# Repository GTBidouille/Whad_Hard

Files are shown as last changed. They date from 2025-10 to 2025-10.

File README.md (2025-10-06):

Bonjour, j'ai commencé à regarder la partie sniffer 40 canaux pour que cela puisse être utilisé par Whad

au début j'étais parti sur l'idée de faire 40 dongles et de les coller sur un hub usb mais je n'ai pas trouvé de hub usb assez grand, donc je serai parti sur une cascade de hub usb. Il aurait fallu gérer les tensions puis je me suis dit que peut être on pouvait faire differement

je suis parti dans l'idée de passer par un microntrolleur qui pourrait parler via SPI au module rf52840 ( en passant par la partie DMA, soit en demander au module de me prévenir quand il a des données, soit en faisant une lecture réguliere)

après mes recherches, je penche pour un STM32 ( H7,F7 ou encore H5 car ils peuvent gérer 6 bus SPI different). Cela me permettrait de limiter le nombre de CS ( en gros je lis les modules 1 de chaque carte enfant), je peux me servir du DMA pour limiter l'utilisation des modules RF, je peux buffeuriser, la vitesse est suffisante pour gerer mes 40 modules ( 5 x 8 en fait) et du coup je peux donner un résultat des 40 canaux en une seule fois.

je pense que je dois pouvoir avoir un CS commun pour les cartes sans avoir à passer par une porte NAND par exemple, il faut juste que je fasse attention au pull-up ou pull-down 

concernant la carte, j'ai choisi  la NUCLEO-F767ZI (STM32F767ZI) car elle semble convenir au besoin pour un cout plus bas que les autres. Le STM32F767ZI peut revenir à 11€ piece et la NUCLEO-F767ZI on peut la trouver à 23€

pour la partie utilisation du rf52840, je vais me baser sur le pdf schematics and PCB ainsi que sur la partie datasheet. Le cout d'un rf5280 est entre 4 et 9 €

questions: 
	- est ce que l'on part sur des antennes PCB, céramiques ou filaire
	- je pense partir sur du polling régulier mais je pourrais gérer les flux via des INT ( peut se modifier sans avoir a toucher au PCB)

je vais mettre 

broches utilisées sur le F767ZI 

pour la partie SPI ( tous en full duplex master)
| bus SPI | Miso | Mosi | CLK |
|---|---|---|---|
| SPI1 | PA6 | PA7 | PA5 | 
| SPI2 | PC2 | PC1 | PB10 | 
| SPI3 | PC11 | PB2 | PC10 | 
| SPI4 | PE5 | PE6 | PE2 | 
| SPI5 | PF8 | PF9 | PF7 | 

pour la partie CS : 
- CS1:PF13
- CS2:PF14
- CS3:PF15
- CS4:PG0
- CS5:PG1
- CS6:PE7
- CS7:PE8
- CS8:PE9

pour la partie présence
- P1:PF0
- P2:PF1
- P3:PF2
- P4:PF3
- P5:PF4

pour chaque SPI, le DMA sera activé aussi bien en TX que RX. On peut choisir le mode normal ou circular, je pense que normal est plus adapté

sur le rf52840

- p1.04 : Mosi
- p1.02 : CLK
- p1.06 : Miso
- p1.09 : /CS

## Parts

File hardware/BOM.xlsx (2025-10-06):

nom | valeur | taille | ref | nombre
X1 | 32Mhz | 2016 | C37635331 | 1
X2 | 32.768Khz | 2012 | C96341 (https://www.lcsc.com/product-detail/C96341.html)
C1, C2,C17,C18 | 12pf | 603 | C5448886 | 4
C11 | 100pf | 603
L1 | 4,7nH | 603 | C37634064 (https://www.lcsc.com/product-detail/C37634064.html)
R1 | O | 603
C3 | 0,8pF | 603
C4 | 0,5pF | 603
C26 | 1,5pF | 603
c9 | 820pF | 603
C8,C5 | 100nF | 603
R2 | 10Kohm | 603
C9 | 820pF | 603
C16 | 47nF | 603
L2,L4 | 10µH | 603 | C86083
L3 | 15nH | 402 | C381880 (https://www.lcsc.com/product-detail/C381880.html)
C15 | 1µF | 603
led1 | blanc | 603
led2_r | rouge | 603
led2_g | vert | 603
led2_b | bleu | 603
R3,R4,R5,R6 | 220 | 603
C12 | 4,7µF | 603
 |  | 1206 | C89334
 | rf52840 | 73-VFQFN | https://www.digikey.fr/fr/products/detail/nordic-semiconductor-asa/NRF52840-QIAA-R/7725407

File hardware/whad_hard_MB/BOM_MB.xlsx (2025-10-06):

nom | valeur | taille | ref | nombre
PCIE |  | X1 | C5711219 | 5

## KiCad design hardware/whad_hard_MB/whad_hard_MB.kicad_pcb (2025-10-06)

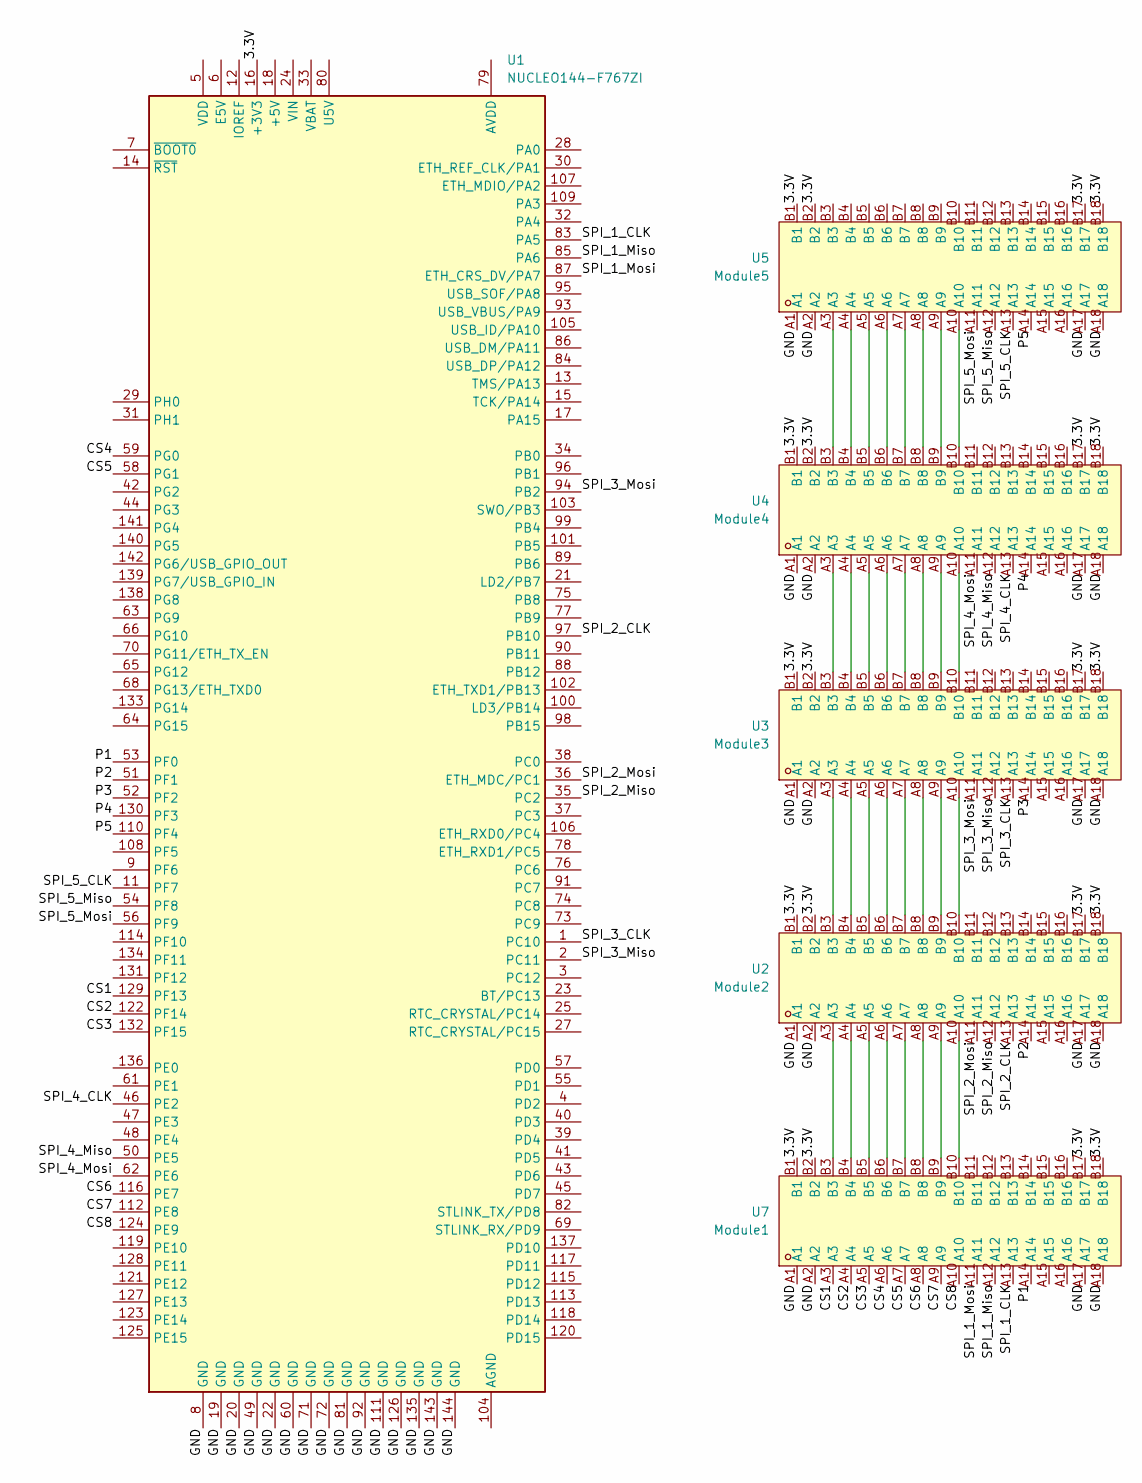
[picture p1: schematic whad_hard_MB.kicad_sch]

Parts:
U1: NUCLEO144-F767ZI; ST_Morpho_Connector_144_STLink
U2: Module2; CONN-TH_X3183WV-36B1-46V15; LCSC Part C5711219
U3: Module3; CONN-TH_X3183WV-36B1-46V15; LCSC Part C5711219
U4: Module4; CONN-TH_X3183WV-36B1-46V15; LCSC Part C5711219
U5: Module5; CONN-TH_X3183WV-36B1-46V15; LCSC Part C5711219
U7: Module1; CONN-TH_X3183WV-36B1-46V15; LCSC Part C5711219

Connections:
/3.3V: U1.16 (+3V3), U2.B1, U2.B2, U2.B17, U2.B18, U3.B1, U3.B2, U3.B17, U3.B18, U4.B1, U4.B2, U4.B17, U4.B18, U5.B1, U5.B2, U5.B17, U5.B18, U7.B1, U7.B2, U7.B17, U7.B18
/CS1: U1.129 (PF13), U7.A3
/CS2: U1.122 (PF14), U7.A4
/CS3: U1.132 (PF15), U7.A5
/CS4: U1.59 (PG0), U7.A6
/CS5: U1.58 (PG1), U7.A7
/CS6: U1.116 (PE7), U7.A8
/CS7: U1.112 (PE8), U7.A9
/CS8: U1.124 (PE9), U7.A10
/GND: U1.8 (GND), U1.19 (GND), U1.20 (GND), U1.22 (GND), U1.49 (GND), U1.60 (GND), U1.71 (GND), U1.72 (GND), U1.81 (GND), U1.92 (GND), U1.111 (GND), U1.126 (GND), U1.135 (GND), U1.143 (GND), U1.144 (GND), U2.A1, U2.A2, U2.A17, U2.A18, U3.A1, U3.A2, U3.A17, U3.A18, U4.A1, U4.A2, U4.A17, U4.A18, U5.A1, U5.A2, U5.A17, U5.A18, U7.A1, U7.A2, U7.A17, U7.A18
/P1: U1.53 (PF0), U7.A14
/P2: U1.51 (PF1), U2.A14
/P3: U1.52 (PF2), U3.A14
/P4: U1.130 (PF3), U4.A14
/P5: U1.110 (PF4), U5.A14
/SPI_1_CLK: U1.83 (PA5), U7.A13
/SPI_1_Miso: U1.85 (PA6), U7.A12
/SPI_1_Mosi: U1.87 (ETH_CRS_DV/PA7), U7.A11
/SPI_2_CLK: U1.97 (PB10), U2.A13
/SPI_2_Miso: U1.35 (PC2), U2.A12
/SPI_2_Mosi: U1.36 (ETH_MDC/PC1), U2.A11
/SPI_3_CLK: U1.1 (PC10), U3.A13
/SPI_3_Miso: U1.2 (PC11), U3.A12
/SPI_3_Mosi: U1.94 (PB2), U3.A11
/SPI_4_CLK: U1.46 (PE2), U4.A13
/SPI_4_Miso: U1.50 (PE5), U4.A12
/SPI_4_Mosi: U1.62 (PE6), U4.A11
/SPI_5_CLK: U1.11 (PF7), U5.A13
/SPI_5_Miso: U1.54 (PF8), U5.A12
/SPI_5_Mosi: U1.56 (PF9), U5.A11
unnamed: U2.A3, U7.B3
unnamed: U2.A4, U7.B4
unnamed: U2.A5, U7.B5
unnamed: U2.A6, U7.B6
unnamed: U2.A7, U7.B7
unnamed: U2.A8, U7.B8
unnamed: U2.A9, U7.B9
unnamed: U2.A10, U7.B10
unnamed: U2.B3, U3.A3
unnamed: U2.B4, U3.A4
unnamed: U2.B5, U3.A5
unnamed: U2.B6, U3.A6
unnamed: U2.B7, U3.A7
unnamed: U2.B8, U3.A8
unnamed: U2.B9, U3.A9
unnamed: U2.B10, U3.A10
unnamed: U3.B3, U4.A3
unnamed: U3.B4, U4.A4
unnamed: U3.B5, U4.A5
unnamed: U3.B6, U4.A6
unnamed: U3.B7, U4.A7
unnamed: U3.B8, U4.A8
unnamed: U3.B9, U4.A9
unnamed: U3.B10, U4.A10
unnamed: U4.B3, U5.A3
unnamed: U4.B4, U5.A4
unnamed: U4.B5, U5.A5
unnamed: U4.B6, U5.A6
unnamed: U4.B7, U5.A7
unnamed: U4.B8, U5.A8
unnamed: U4.B9, U5.A9
unnamed: U4.B10, U5.A10

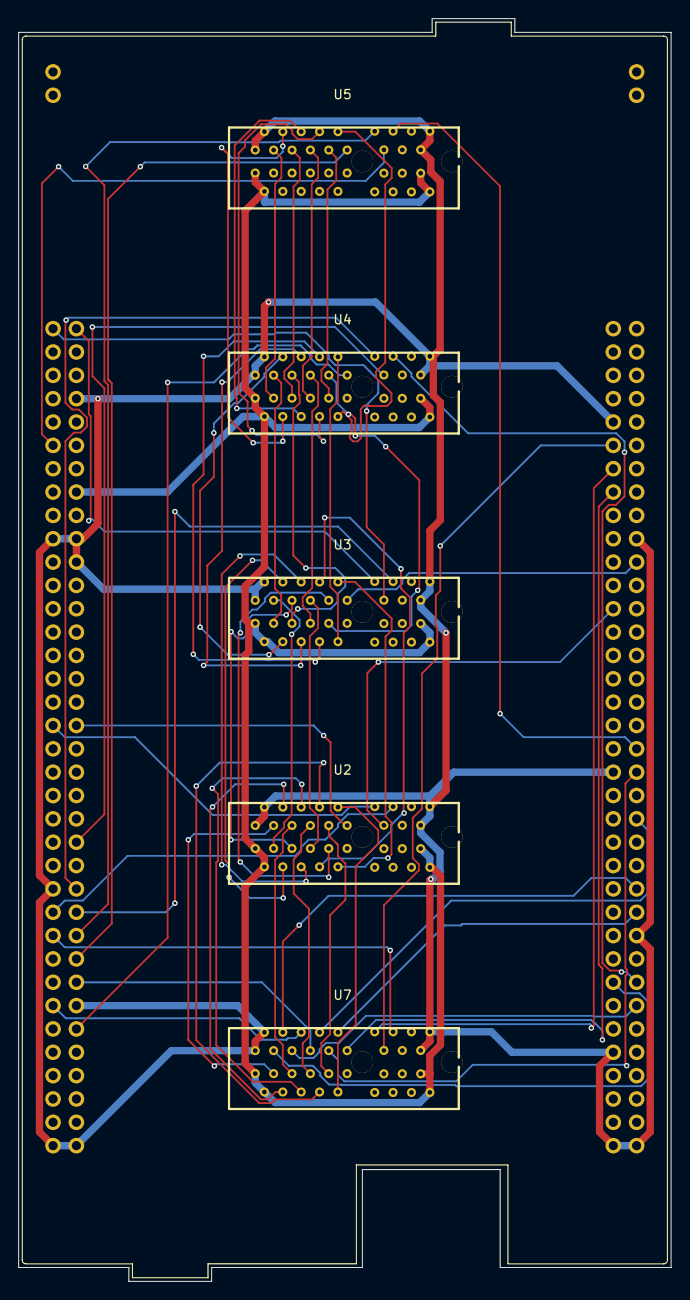
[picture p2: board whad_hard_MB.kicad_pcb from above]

Board: 2 copper layers, 71.0 x 137.4 mm, 6 parts (0 on the bottom side), 62 nets.

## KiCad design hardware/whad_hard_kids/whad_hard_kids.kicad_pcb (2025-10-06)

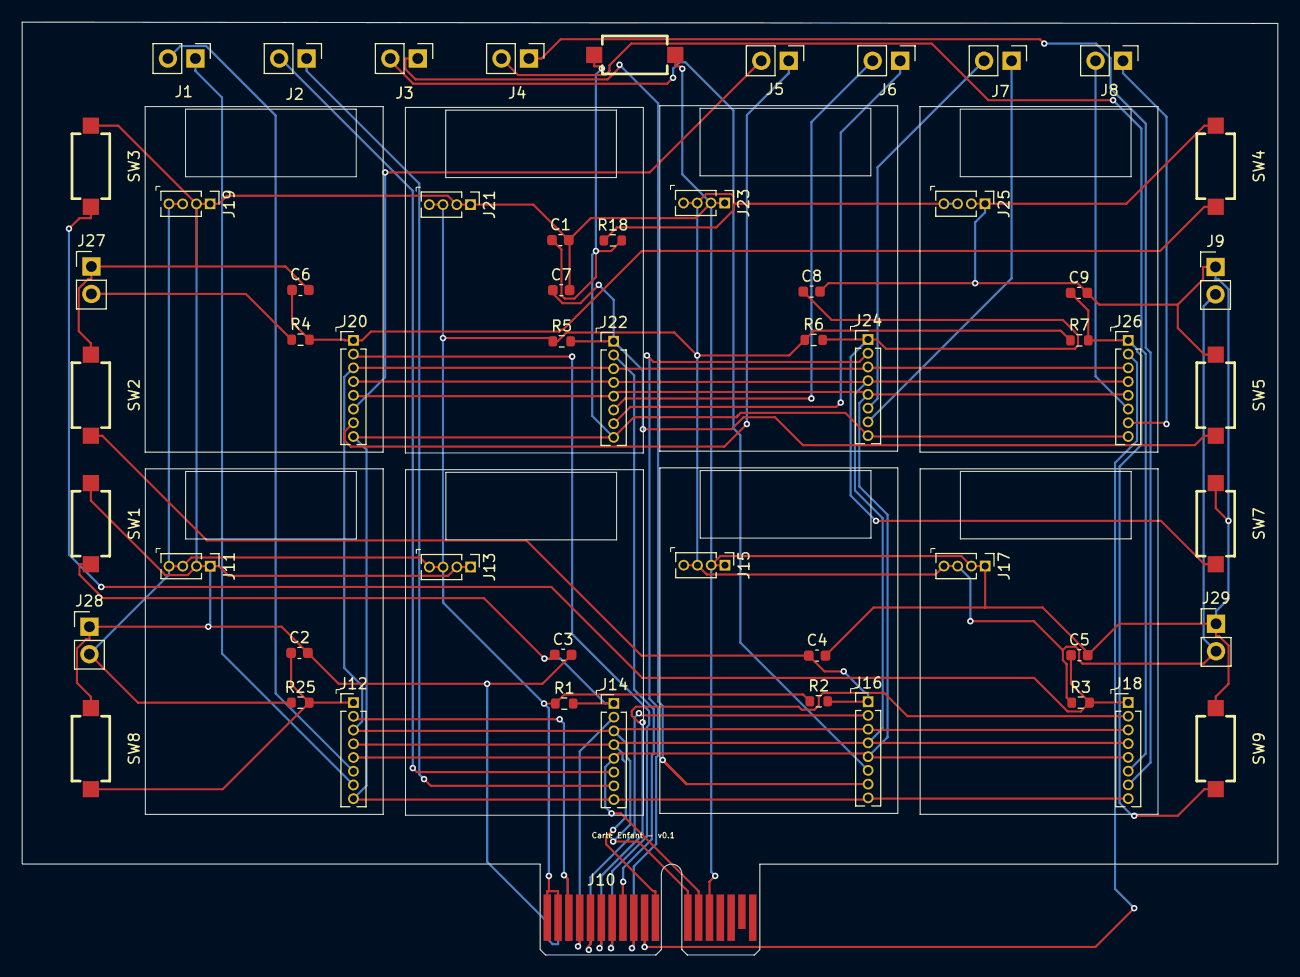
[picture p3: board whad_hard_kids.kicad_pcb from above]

Board: 2 copper layers, 116.1 x 86.2 mm, 56 parts (0 on the bottom side), 38 nets.

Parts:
C1, C2, C3, C4, C5, C6, C7, C8, C9: 100nf; C_0603_1608Metric
J1: SWD-module1; PinHeader_1x02_P2.54mm_Vertical
J2: SWD-module2; PinHeader_1x02_P2.54mm_Vertical
J3: SWD-module3; PinHeader_1x02_P2.54mm_Vertical
J4: SWD-module14; PinHeader_1x02_P2.54mm_Vertical
J5: SWD-module5; PinHeader_1x02_P2.54mm_Vertical
J6: SWD-module6; PinHeader_1x02_P2.54mm_Vertical
J7: SWD-module7; PinHeader_1x02_P2.54mm_Vertical
J8: SWD-module8; PinHeader_1x02_P2.54mm_Vertical
J9, J27, J28, J29: SWD-Alim; PinHeader_1x02_P2.54mm_Vertical
J10: whad_Bus_PCI_Express_x1; BUS_PCIexpress_x1
J11, J13, J15, J17, J19, J21, J23, J25: Conn_01x04_Pin; PinHeader_1x04_P1.27mm_Vertical
J12, J14, J16, J18, J20, J22, J24, J26: Conn_01x08_Pin; PinHeader_1x08_P1.27mm_Vertical
R1, R2, R3, R4, R5, R6, R7, R18, R25: 10K; R_0603_1608Metric
SW1: SWI2; KEY-SMD_L6.0-W3.5-LS8.0
SW2: SWI3; KEY-SMD_L6.0-W3.5-LS8.0
SW3: SWI4; KEY-SMD_L6.0-W3.5-LS8.0
SW4: SWI5; KEY-SMD_L6.0-W3.5-LS8.0
SW5: SWI6; KEY-SMD_L6.0-W3.5-LS8.0
SW6: Reset; KEY-SMD_L6.0-W3.5-LS8.0
SW7: SWI7; KEY-SMD_L6.0-W3.5-LS8.0
SW8: SWI1; KEY-SMD_L6.0-W3.5-LS8.0
SW9: SWI8; KEY-SMD_L6.0-W3.5-LS8.0

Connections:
/3.3V: J9.2, J10.B1 (+3.3V), J10.B2 (+3.3V), J11.3, J11.4, J13.3, J13.4, J15.3, J15.4, J17.3, J17.4, J19.3, J19.4, J21.3, J21.4, J23.3, J23.4, J25.3, J25.4, J27.2, J28.2, J29.2, R1.1, R2.1, R3.1, R4.1, R5.1, R6.1, R7.1, R18.1, R25.1
/CLK: J10.B13 (SPI_CLK), J12.5, J14.5, J16.5, J18.5, J20.5, J22.5, J24.5, J26.5
/CS1: J10.A3 (CS1), J10.B3 (CS1), J12.2
/CS2: J10.A4 (CS2), J10.B4 (CS2), J14.2
/CS3: J10.A5 (CS3), J10.B5 (CS3), J16.2
/CS4: J10.A6 (CS4), J10.B6 (CS4), J18.2
/CS5: J10.A7 (CS5), J10.B7 (CS5), J20.2
/CS6: J10.A8 (CS6), J10.B8 (CS6), J22.2
/CS7: J10.A9 (CS7), J10.B9 (CS7), J24.2
/CS8: J10.A10 (CS8), J10.B10 (CS8), J26.2
/GND: C1.2, C2.2, C3.2, C4.2, C5.2, C6.2, C7.2, C8.2, C9.2, J9.1, J10.A1 (gnd), J10.A2 (gnd), J10.B14 (presence), J11.1, J11.2, J13.1, J13.2, J15.1, J15.2, J17.1, J17.2, J19.1, J19.2, J21.1, J21.2, J23.1, J23.2, J25.1, J25.2, J27.1, J28.1, J29.1, SW1.1, SW2.1, SW3.1, SW4.1, SW5.1, SW6.1, SW7.1, SW8.1, SW9.1
/Miso: J10.B12 (SPI_Miso), J12.3, J14.3, J16.3, J18.3, J20.3, J22.3, J24.3, J26.3
/Mosi: J10.B11 (SPI_Mosi), J12.4, J14.4, J16.4, J18.4, J20.4, J22.4, J24.4, J26.4
/Reset: C1.1, J12.8, J14.8, J16.8, J18.8, J20.8, J22.8, J24.8, J26.8, R18.2, SW6.2
/SWD_CLK_1: J1.1, J12.7
/SWD_CLK_2: J2.1, J14.7
/SWD_CLK_3: J3.1, J16.7
/SWD_CLK_4: J4.1, J18.7
/SWD_CLK_5: J5.1, J20.7
/SWD_CLK_6: J6.1, J22.7
/SWD_CLK_7: J7.1, J24.7
/SWD_CLK_8: J8.1, J26.7
/SWD_IO_1: J1.2, J12.6
/SWD_IO_2: J2.2, J14.6
/SWD_IO_3: J3.2, J16.6
/SWD_IO_4: J4.2, J18.6
/SWD_IO_5: J5.2, J20.6
/SWD_IO_6: J6.2, J22.6
/SWD_IO_7: J7.2, J24.6
/SWD_IO_8: J8.2, J26.6
/SWI1: C2.1, J12.1, R25.2, SW8.2
/SWI2: C3.1, J14.1, R1.2, SW1.2
/SWI3: C4.1, J16.1, R2.2, SW2.2
/SWI4: C5.1, J18.1, R3.2, SW3.2
/SWI5: C6.1, J20.1, R4.2, SW4.2
/SWI6: C7.1, J22.1, R5.2, SW5.2
/SWI7: C8.1, J24.1, R6.2, SW7.2
/SWI8: C9.1, J26.1, R7.2, SW9.2

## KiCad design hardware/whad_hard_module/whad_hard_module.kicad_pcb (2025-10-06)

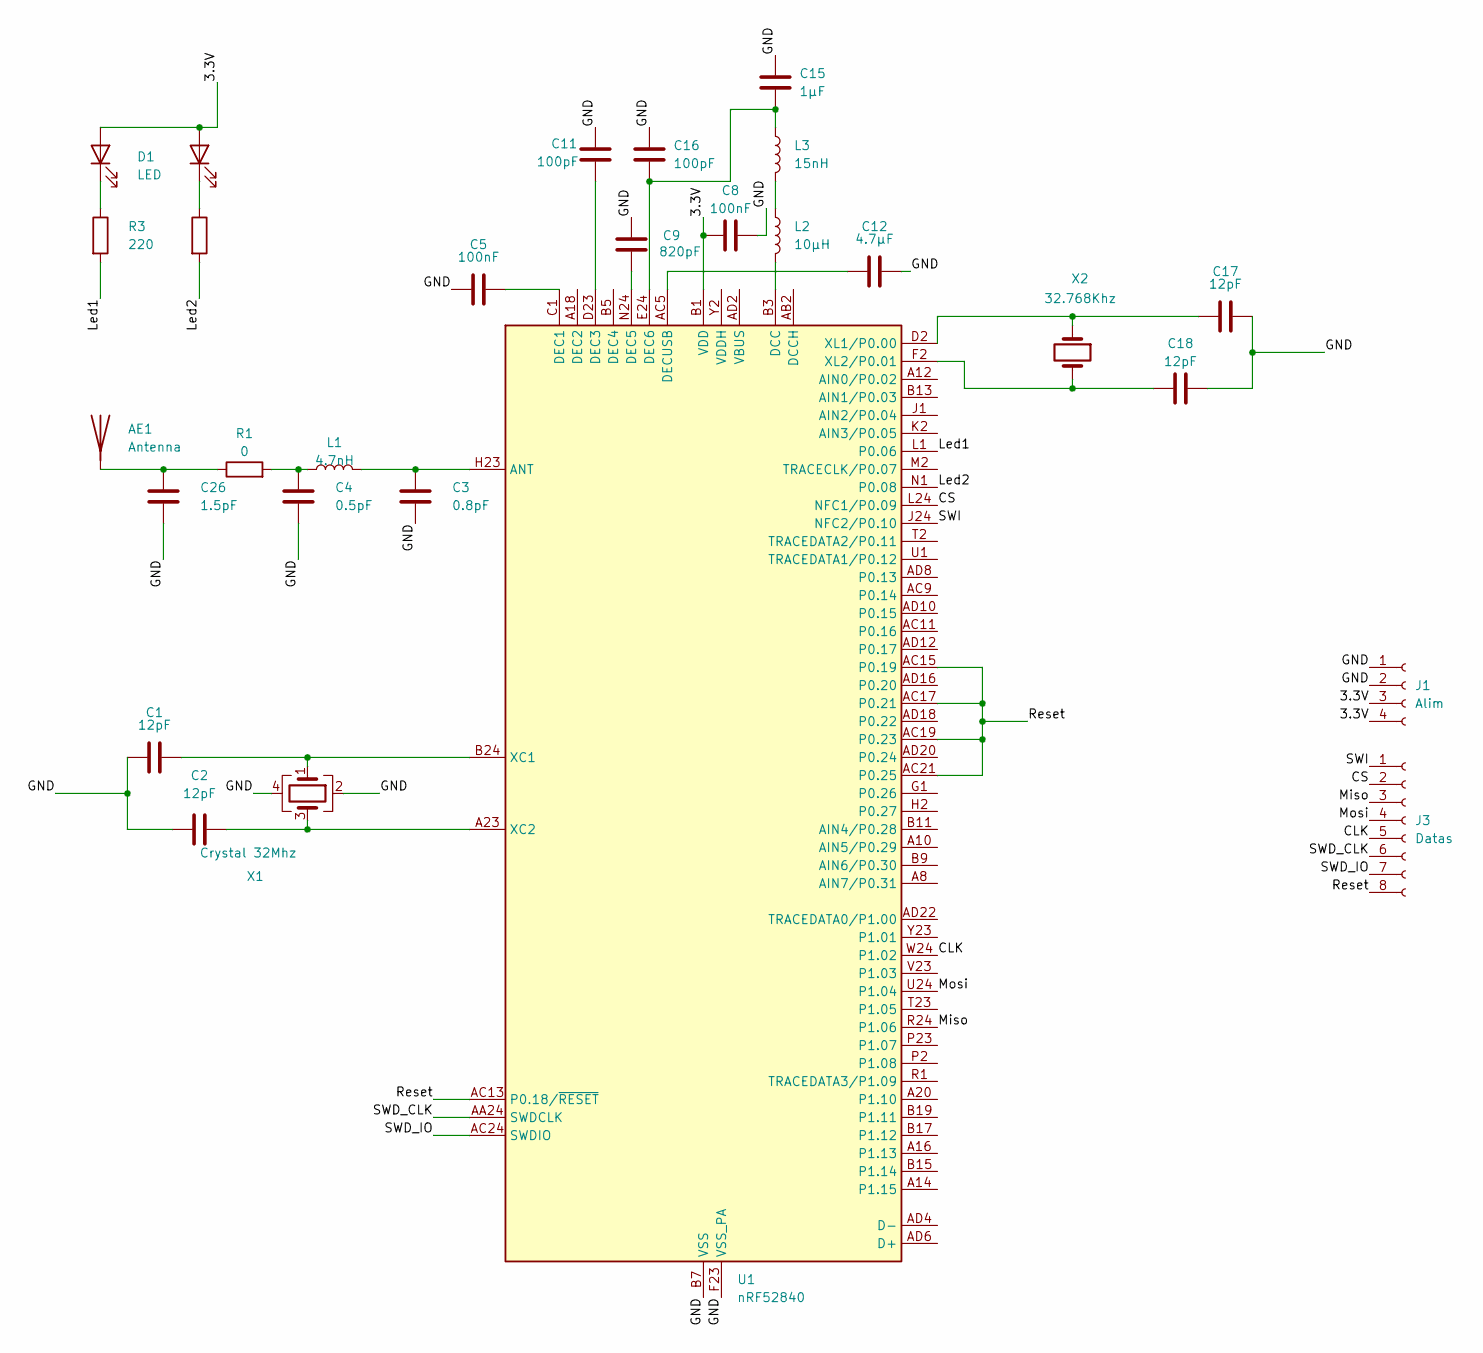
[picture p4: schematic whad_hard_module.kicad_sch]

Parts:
AE1: Antenna; antenne_2_4G
C1, C2, C17, C18: 12pF; C_0603_1608Metric
C3: 0.8pF; C_0603_1608Metric
C4: 0.5pF; C_0603_1608Metric
C5, C8: 100nF; C_0603_1608Metric
C9: 820pF; C_0603_1608Metric
C11, C16: 100pF; C_0603_1608Metric
C12: 4.7µF; C_0603_1608Metric
C15: 1µF; C_0603_1608Metric
C26: 1.5pF; C_0603_1608Metric
D1, D2: LED; LED_0603_1608Metric
J1: Alim; PinHeader_1x04_P1.27mm_Vertical
J3: Datas; PinHeader_1x08_P1.27mm_Vertical
L1: 4.7nH; L_0603_1608Metric
L2: 10µH; L_0603_1608Metric
L3: 15nH; L_0402_1005Metric
R1: 0; R_0603_1608Metric
R3, R4: 220; R_0603_1608Metric
U1: nRF52840; Nordic_AQFN-73-1EP_7x7mm_P0.5mm
X1: Crystal 32Mhz; Crystal_SMD_2016-4Pin_2.0x1.6mm
X2: 32.768Khz; Crystal_SMD_2012-2Pin_2.0x1.2mm

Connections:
/3.3V: C8.2, D1.2 (A), D2.2 (A), J1.3, J1.4, U1.A22 (VDD), U1.AD14 (VDD), U1.AD23 (VDD), U1.B1 (VDD), U1.W1 (VDD)
/CLK: J3.5, U1.W24 (P1.02)
/CS: J3.2, U1.L24 (NFC1/P0.09)
/GND: C1.2, C2.2, C3.1, C4.1, C5.2, C8.1, C9.2, C11.2, C12.2, C15.2, C16.2, C17.2, C18.2, C26.1, J1.1, J1.2, U1.B7 (VSS), U1.EP (VSS), U1.F23 (VSS_PA), X1.2, X1.4
/Led1: R3.2, U1.L1 (P0.06)
/Led2: R4.2, U1.N1 (P0.08)
/Miso: J3.3, U1.R24 (P1.06)
/Mosi: J3.4, U1.U24 (P1.04)
/Reset: J3.8, U1.AC13 (P0.18/~RESET), U1.AC15 (P0.19), U1.AC17 (P0.21), U1.AC19 (P0.23), U1.AC21 (P0.25)
/SWD_CLK: J3.6, U1.AA24 (SWDCLK)
/SWD_IO: J3.7, U1.AC24 (SWDIO)
/SWI: J3.1, U1.J24 (NFC2/P0.10)
unnamed: AE1.1 (A), C26.2, R1.1
unnamed: C4.2, L1.1, R1.2
unnamed: D1.1 (K), R3.1
unnamed: D2.1 (K), R4.1
unnamed: L2.1, L3.2
unnamed: C3.2, L1.2, U1.H23 (ANT)
unnamed: L2.2, U1.B3 (DCC)
unnamed: C5.1, U1.C1 (DEC1)
unnamed: C11.1, U1.D23 (DEC3)
unnamed: C9.1, U1.N24 (DEC5)
unnamed: C15.1, C16.1, L3.1, U1.E24 (DEC6)
unnamed: C12.1, U1.AC5 (DECUSB)
unnamed: C1.1, U1.B24 (XC1), X1.1
unnamed: C2.1, U1.A23 (XC2), X1.3
unnamed: C17.1, U1.D2 (XL1/P0.00), X2.1
unnamed: C18.1, U1.F2 (XL2/P0.01), X2.2

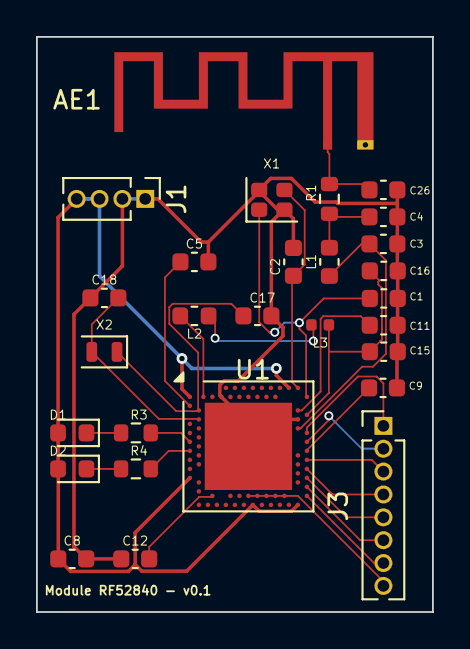
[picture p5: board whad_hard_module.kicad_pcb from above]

Board: 2 copper layers, 22.0 x 31.9 mm, 28 parts (0 on the bottom side), 28 nets.

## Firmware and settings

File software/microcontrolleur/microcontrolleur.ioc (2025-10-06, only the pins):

Mcu.UserName=STM32F767ZITx
PA5.Signal=SPI1_SCK
PA6.Signal=SPI1_MISO
PA7.Signal=SPI1_MOSI
PB10.Signal=SPI2_SCK
PB2.Signal=SPI3_MOSI
PC1.Signal=SPI2_MOSI
PC10.Signal=SPI3_SCK
PC11.Signal=SPI3_MISO
PC2.Signal=SPI2_MISO
PE2.Signal=SPI4_SCK
PE5.Signal=SPI4_MISO
PE6.Signal=SPI4_MOSI
PE7.GPIO_Label=CS6
PE7.Signal=GPIO_Output
PE8.GPIO_Label=CS7
PE8.Signal=GPIO_Output
PE9.GPIO_Label=CS8
PE9.Signal=GPIO_Output
PF13.GPIO_Label=CS1
PF13.Signal=GPIO_Output
PF14.GPIO_Label=CS2
PF14.Signal=GPIO_Output
PF15.GPIO_Label=CS3
PF15.Signal=GPIO_Output
PF7.Signal=SPI5_SCK
PF8.Signal=SPI5_MISO
PF9.Signal=SPI5_MOSI
PG0.GPIO_Label=CS4
PG0.Signal=GPIO_Output
PG1.GPIO_Label=CS5
PG1.Signal=GPIO_Output
